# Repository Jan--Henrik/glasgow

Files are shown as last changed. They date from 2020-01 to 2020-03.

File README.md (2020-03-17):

# Glasgow Debug Tool

# This is not the official revC2 branch, I just added USB-C for myself!

**Want one? [Subscribe here](https://mailchi.mp/44980ff6f0ab/glasgow-announcements).**

**Let's chat! Our IRC channel is [#glasgow at freenode.net](https://webchat.freenode.net/?channels=glasgow); our discussion forum is [glasgow.whitequark.org](https://glasgow.whitequark.org/).**

**Important note: if you are looking to assemble boards yourself, use only revC1.**

## What is Glasgow?

Glasgow is a tool for exploring digital interfaces, aimed at embedded developers, reverse engineers, digital archivists, electronics hobbyists, and everyone else who wants to communicate to a wide selection of digital devices with high reliability and minimum hassle. It can be attached to most devices without additional active or passive components, and includes extensive protection from unexpected conditions and operator error.

The Glasgow hardware can support many digital interfaces because it uses reconfigurable logic. Instead of only offering a small selection of standard hardware supported interfaces, it uses an FPGA to adapt on the fly to the task at hand without compromising on performance or reliability, even for unusual, custom or obsolete interfaces.

The Glasgow software is a set of building blocks designed to eliminate incidental complexity. Each interface is packaged into a self-contained *applet* that can be used directly from the command line, or reused as a part of a more complex system. Using Glasgow does not require any programming knowledge, although it becomes much more powerful if you know a bit of Python.

## What can I do with Glasgow?

Some of the tasks Glasgow can do well are:

  * communicate via UART,
    * automatically determine and follow the baud rate of device under test,
  * initiate transactions via SPI or I²C,
  * read and write 24-series EEPROMs,
  * read and write 25-series Flash memories,
    * determine memory parameters via SFDP,
  * read and write ONFI-compatible Flash memories,
    * determine memory parameters via ONFI parameter page,
  * program and verify AVR microcontrollers with SPI interface,
  * automatically determine unknown JTAG pinout,
  * play back JTAG SVF files,
  * debug ARC processors via JTAG,
  * debug some MIPS processors via EJTAG,
  * program and verify XC9500XL CPLDs via JTAG,
  * synthesize sound using a Yamaha OPLx/OPM chip and play it in real time on a webpage,
  * read raw modulated data from 5.25"/3.5" floppy drives,
  * ... and more!

Everything above can be done with only a Glasgow revC board, some wires, and depending on the device under test, external power.

## How does using Glasgow look like?

Watch a typical command-line workflow in this screencast:

asciicast (https://asciinema.org/a/i9edqaUBVLLw7mRZCpdxe91Fu)

## What hardware does Glasgow use?

The Glasgow hardware evolves over time, with each major milestone called a "revision". Although all revisions are, and will always be supported with the same software, they vary significantly in their capabilities, and the chosen revision will limit the possible tasks.

Glasgow boards use a version in the `revXN` format, where `X` is a revision letter (increased on major design changes) and `N` is a stepping number (increased on any layout or component changes). For example, `revC0` is the first stepping of revision C.

### revA/revB

Revisions A and B have not been produced in significant amounts, contain major design issues, and are therefore mostly of historical interest. Nevertheless, everyone who has one of the revA/revB boards can keep using them—forever.

### revC

Overview of the Glasgow PCB

Revision C is the latest revision and is being prepared for mass production. It provides 16 I/O pins with a maximum frequency of approx. 100 MHz\*, independent direction control and independent programmable pull-up/pull-down resistors. The I/O pins are grouped into two I/O ports that can use any voltage from 1.8 V to 5 V, sense and monitor I/O voltage of the device under test, as well as provide up to 150 mA of power. The board uses USB 2 for power, configuration, and communication, achieving up to 336 Mbps (42 MB/s) of sustained combined throughput.

<sub>\* Maximum frequency achievable in practice depends on many factors and will vary greatly with specific interface and applet design. 24 MHz non-DDR can be achieved for most interfaces with minimal effort.</sub>

## What software does Glasgow use?

Glasgow is written entirely in Python 3. The interface logic that runs on the FPGA is described using [Migen](https://m-labs.hk/migen/), which is a Python-based domain specific language. The supporting code that runs on the host PC is written in Python with [asyncio](https://docs.python.org/3/library/asyncio.html). This way, the logic on the FPGA can be assembled on demand for any requested configuration, keeping it as fast and compact as possible, and code can be shared between gateware and software, removing the need to add error-prone "glue" boilerplate.

Glasgow would not be possible without the [open-source iCE40 FPGA toolchain](http://www.clifford.at/icestorm/), which is not only very reliable but also extremely fast. It is so fast that FPGA bitstreams are not cached (beyond not rebuilding the bitstream already on the device), as it only takes a few seconds to build one from scratch for something like an UART. When developing a new applet it is rarely necessary to wait for the toolchain.

Implementing reliable, high-performance USB communication is not trivial—packetization, buffering, and USB quirks add up. Glasgow abstracts away USB: on the FPGA, the applet gateware writes to or reads from a FIFO, and on the host, applet software writes to or reads from a socket-like interface. Idiomatic Python code can communicate at maximum USB 2 bulk bandwidth on a modern PC without additional effort. Moreover, when a future Glasgow revision will use Ethernet in addition to USB, no changes to applet code will be required.

Debugging new applets can be hard, especially if bidirectional buses are involved. Glasgow provides a built-in cycle-accurate logic analyzer that can relate the I/O pin level and direction changes to commands and responses received and sent by the applet. The logic analyzer compresses waveforms and can pause the applet if its buffer is about to overflow.

## How do I use Glasgow?

### ... with Linux?

**Multiple people have reported various issues with the installation instructions below. If any part of these does not work, please file it as a bug, so that the experience can be made more smooth for everyone.**

You will need git, build tools, sdcc, Python 3.7 (or a newer version, in which case replace `3.7` with that version below). On a Debian or Ubuntu system these can be installed with:

    apt-get install --no-install-recommends git build-essential sdcc \
      python3.7 python3-setuptools python3-libusb1 python3-aiohttp python3-bitarray python3-crcmod

You will also need Yosys and nextpnr-ice40, both from the master branch. Follow the setup instructions for [Yosys](https://github.com/yosysHQ/yosys/#setup) and [nextpnr](https://github.com/YosysHQ/nextpnr/#nextpnr-ice40).

Obtain the source code:

    git clone https://github.com/GlasgowEmbedded/glasgow
    cd glasgow
    git submodule update --init vendor/libfx2

Configure your system to allow unprivileged access (for anyone in the `plugdev` group) to the Glasgow hardware:

    sudo cp config/99-glasgow.rules /etc/udev/rules.d

Install the dependencies and the binaries for the current user:

    cd software
    python3.7 setup.py develop --user

The binaries are placed in `$HOME/.local/bin`, so be sure to add that directory to the `PATH` environment variable; after this, you can run `glasgow` from a terminal. Instead of adjusting `PATH` it is also possible to use `python3.7 -m glasgow.cli`.

When you connect your board for the first time after assembly you have to flash it initially, run the following command.

    glasgow factory --rev {A0|B0|C0|C1}

To update the source code, do:

    cd glasgow
    git pull
    cd software
    python3.7 setup.py build_ext

### ... with Windows?

Although first-class Windows support is an important goal and Glasgow already works on Windows, the installation process is not yet ready.

## Who made Glasgow?

  * [@whitequark](https://github.com/whitequark) came up with the design, coordinates the project and implements most of gateware and software;
  * [@awygle](https://github.com/awygle) designed the power/analog port circuitry and helped with layout of revB;
  * [@marcan](https://github.com/marcan) improved almost every aspect of hardware for revC;
  * [@esden](https://github.com/esden) is handling batch manufacturing;
  * [@smunaut](https://github.com/smunaut) provided advice crucial for stability and performance of USB communication;
  * [@electronic_eel](https://github.com/electronic_eel) designed the test jig and advanced protection circuitry;
  * ... and many [other people](https://github.com/GlasgowEmbedded/Glasgow/graphs/contributors).

## License

Glasgow is distributed under the terms of both 0-clause BSD license as well as Apache 2.0 license.

See [LICENSE-0BSD](LICENSE-0BSD.txt) and [LICENSE-Apache-2.0.txt](LICENSE-Apache-2.0.txt) for details.

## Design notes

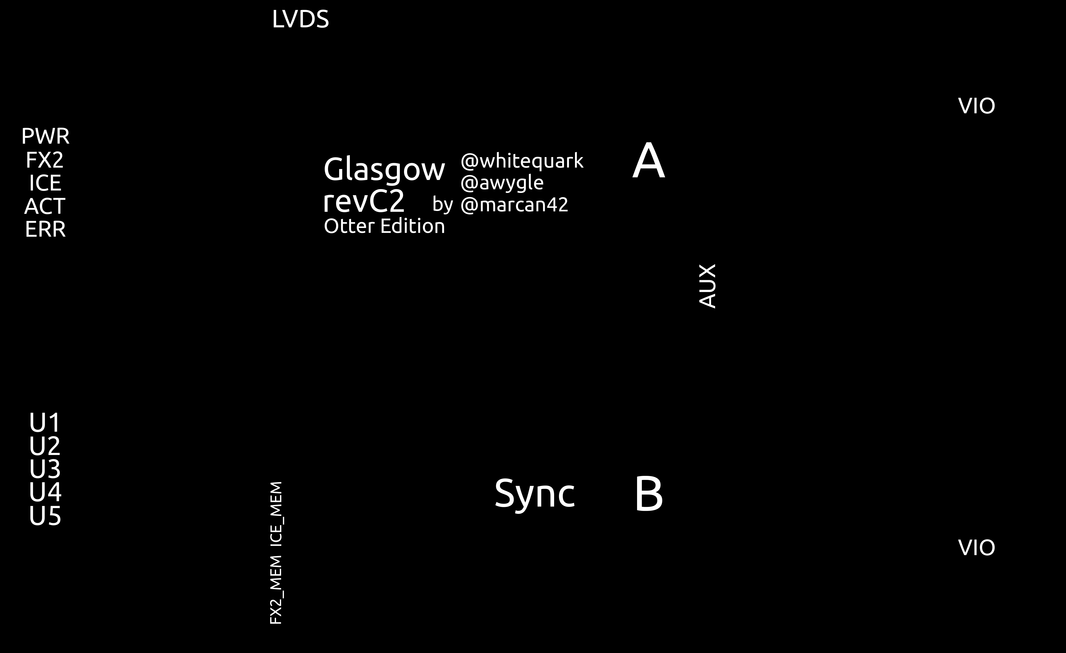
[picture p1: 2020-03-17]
hardware/boards/glasgow/revC1-otter-edition/t_preview.png

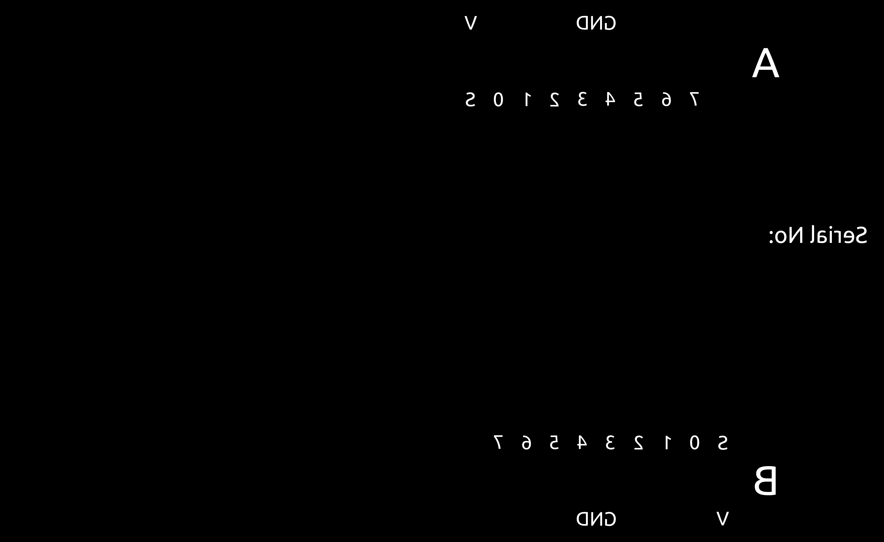
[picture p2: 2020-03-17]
hardware/boards/glasgow/revC1-otter-edition/b_preview.png

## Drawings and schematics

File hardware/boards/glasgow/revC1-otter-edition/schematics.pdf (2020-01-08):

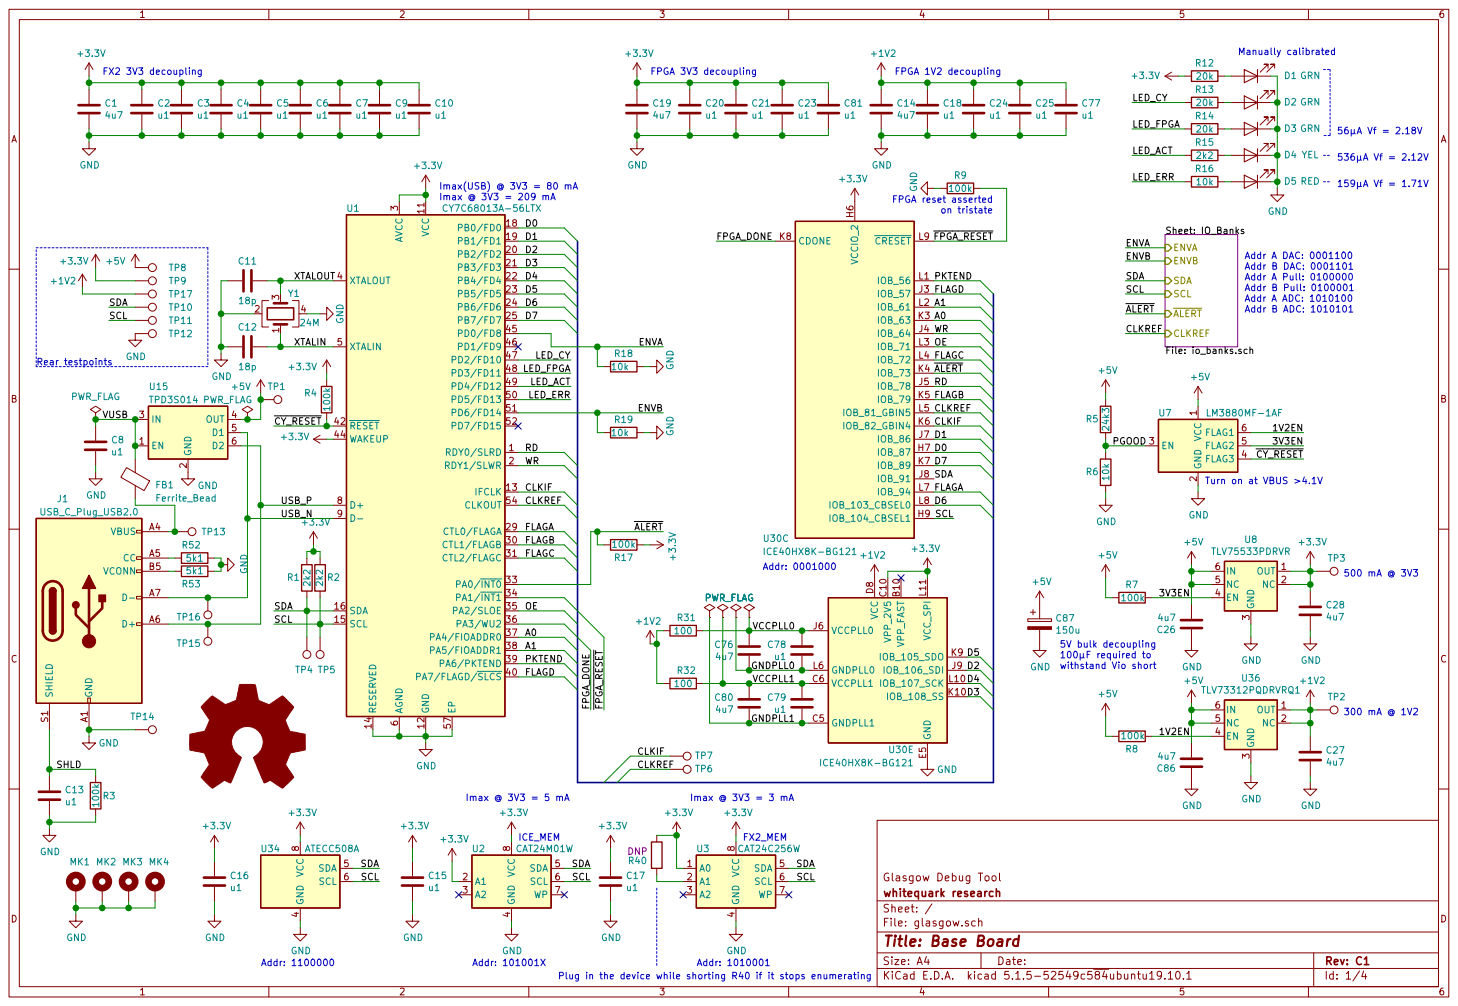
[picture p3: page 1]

3 CTL1/FLAGB 30 CTL2/FLAGC 31 PA0/INT0 33 PA1/INT1 34 PA2/SLOE 35 PA3/WU2 36 PA4/FIOADDR0 37 PA5/FIOADDR1 38 PA6/PKTEND 39 XTALOUT 4 PA7/FLAGD/SLCS 40 RESET 42 WAKEUP 44 PD0/FD8 45 PD1/FD9 46 PD2/FD10 47 PD3/FD11 48 PD4/FD12 49 XTALIN 5 PD5/FD13 50 PD6/FD14 51 PD7/FD15 52 CLKOUT 54 EP 57 AGND

Sheet: IO_Banks File: io_banks.sch ENVA

Addr A DAC: 0001100 Addr B DAC: 0001101 Addr A Pull: 0100000 Addr B Pull: 0100001 Addr A ADC: 1010100 Addr B ADC: 1010101

150u GND
5V bulk decoupling
100µF required to withstand Vio short

4 SDA 5 SCL 6 WP 7 VCC

Glasgow Debug Tool
File: glasgow.sch Sheet: / whitequark research

Id: 1/4 Title: Base Board

Plug in the device while shorting R40 if it stops enumerating

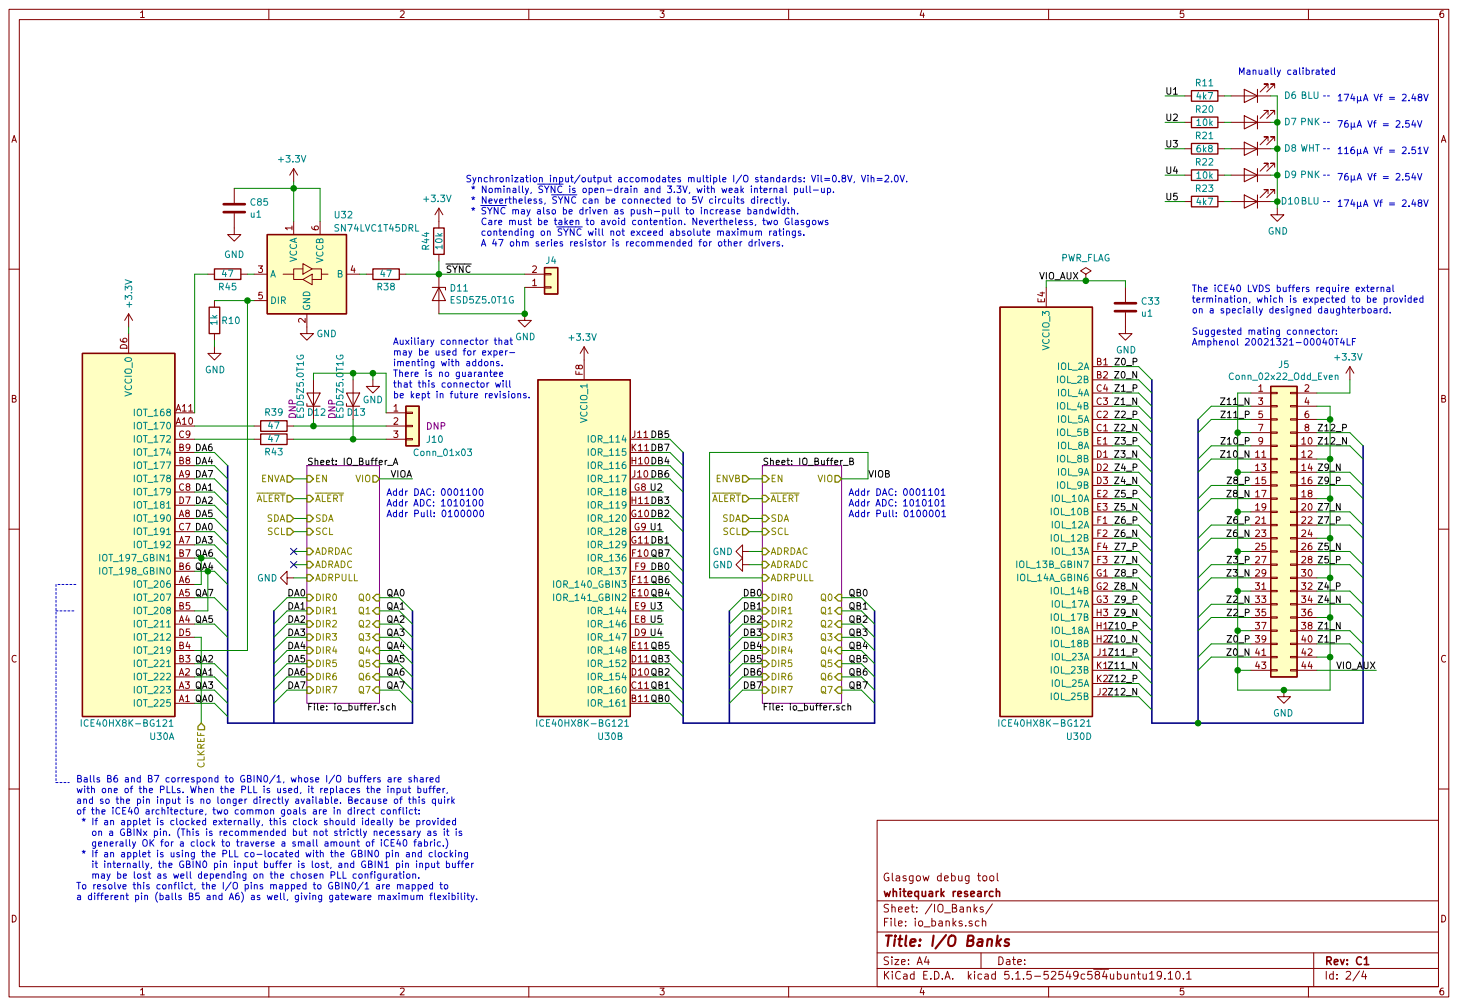
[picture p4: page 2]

Synchronization input/output accomodates multiple I/O standards: Vil=0.8V, Vih=2.0V.
* Nominally, SYNC is open-drain and 3.3V, with weak internal pull-up.
* Nevertheless, SYNC can be connected to 5V circuits directly.
* SYNC may also be driven as push-pull to increase bandwidth.
Care must be taken to avoid contention. Nevertheless, two Glasgows
contending on SYNC will not exceed absolute maximum ratings.

The iCE40 LVDS buffers require external
termination, which is expected to be provided
on a specially designed daughterboard.

may be used for exper-
imenting with addons.
There is no guarantee
that this connector will be kept in future revisions. Addr DAC: 0001100 Addr ADC: 1010100 Addr Pull: 0100000
DIR0 DIR2 DIR4 DIR6 DIR1 DIR3 DIR5 DIR7 ADRPULLVIO
SCL ALERT ADRDAC
File: io_buffer.sch Q1 Q2 Q3 Q4 Q5 Q6 Q7 Q0 SDA

Glasgow debug tool Sheet: IO_Buffer_A

Balls B6 and B7 correspond to GBIN0/1, whose I/O buffers are shared
with one of the PLLs. When the PLL is used, it replaces the input buffer,
and so the pin input is no longer directly available. Because of this quirk
of the iCE40 architecture, two common goals are in direct conflict:
* If an applet is clocked externally, this clock should ideally be provided
on a GBINx pin. (This is recommended but not strictly necessary as it is
generally OK for a clock to traverse a small amount of iCE40 fabric.)
* If an applet is using the PLL co-located with the GBIN0 pin and clocking
it internally, the GBIN0 pin input buffer is lost, and GBIN1 pin input buffer
may be lost as well depending on the chosen PLL configuration.
To resolve this conflict, the I/O pins mapped to GBIN0/1 are mapped to
a different pin (balls B5 and A6) as well, giving gateware maximum flexibility.

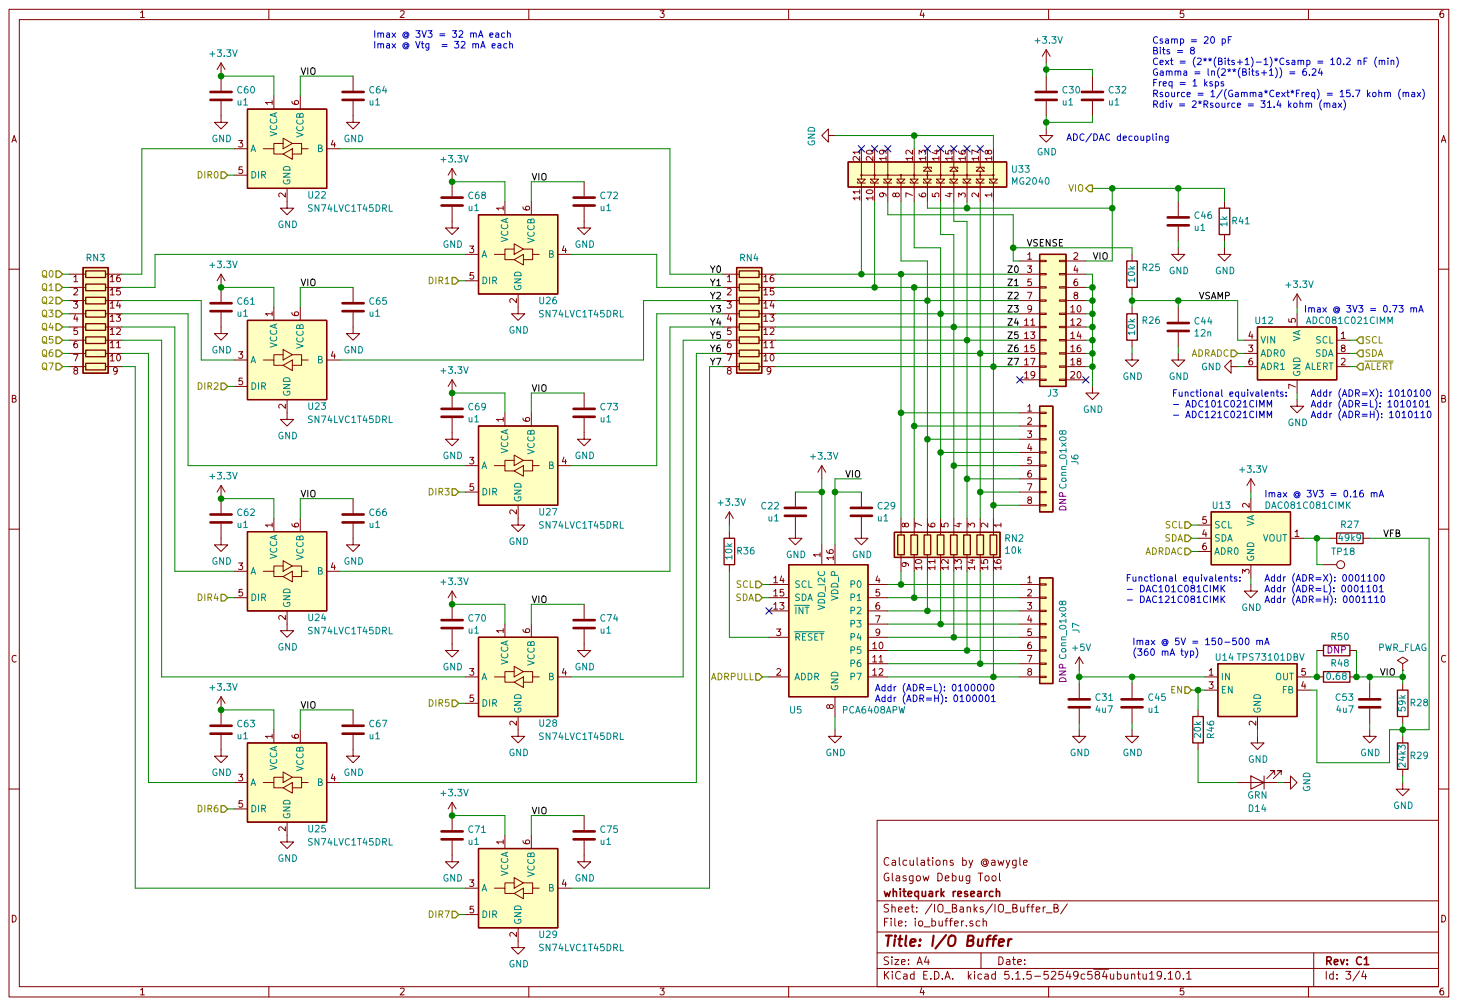
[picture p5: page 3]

Imax @ 3V3 = 32 mA each
Imax @ Vtg = 32 mA each

Csamp = 20 pF Bits = 8 Cext = (2**(Bits+1)-1)*Csamp = 10.2 nF (min)
u1 GND

Gamma = ln(2**(Bits+1)) = 6.24
Freq = 1 ksps
Rsource = 1/(Gamma*Cext*Freq) = 15.7 kohm (max)
Rdiv = 2*Rsource = 31.4 kohm (max)

2 EN 3 FB 4 OUT 5 U14 TPS73101DBV GND GND

Calculations by @awygle GND GND

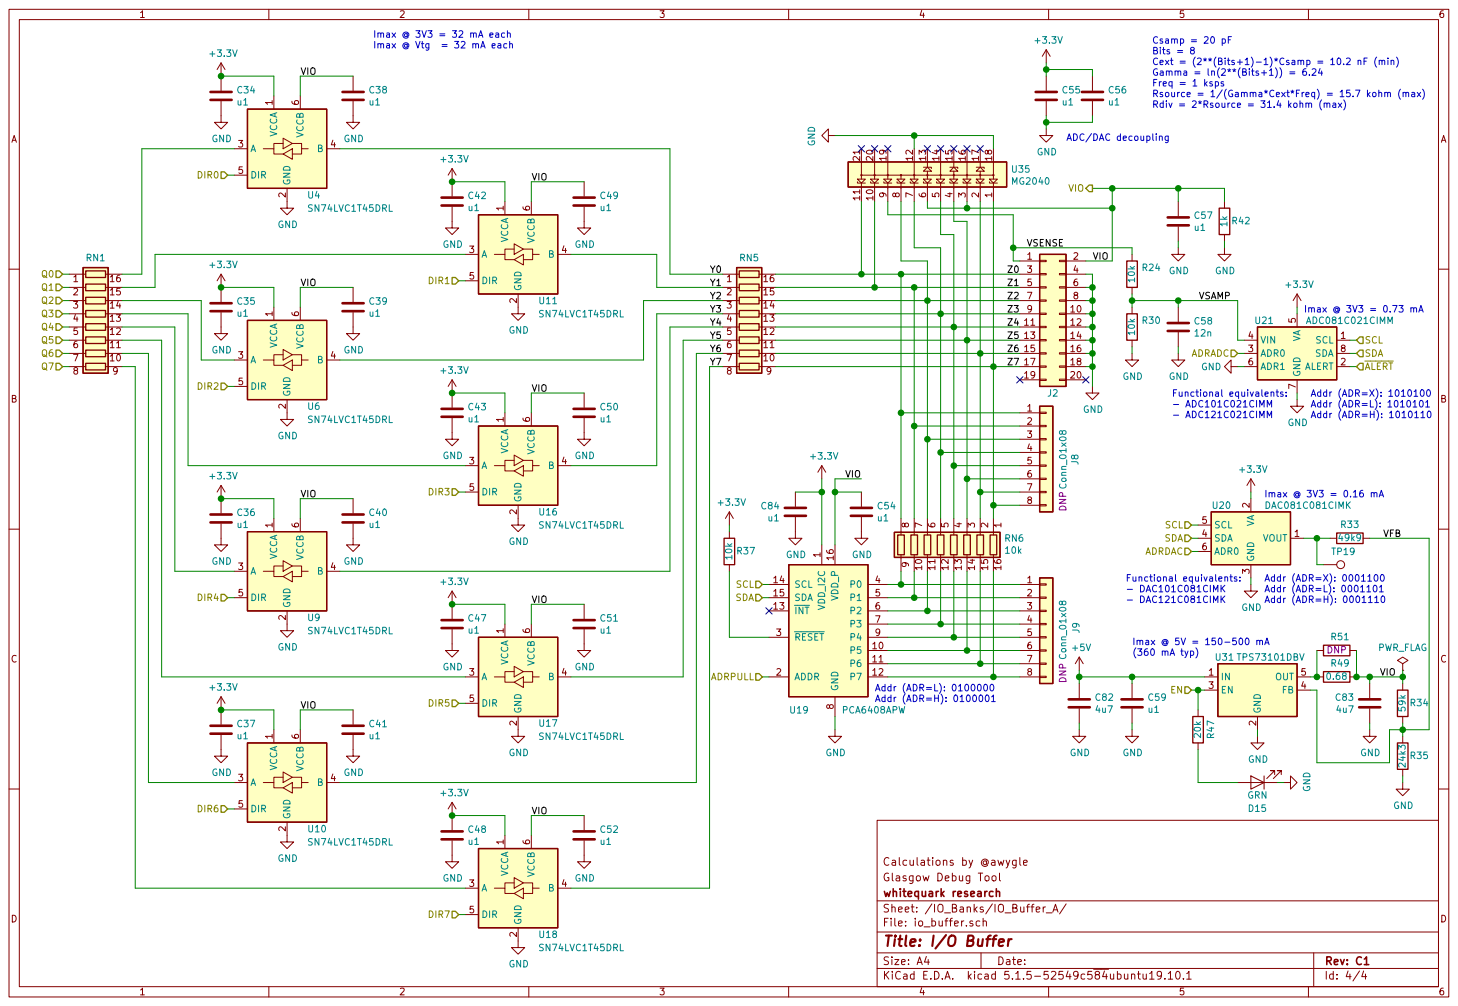
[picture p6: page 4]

Imax @ 3V3 = 32 mA each
Imax @ Vtg = 32 mA each

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

2 EN 3 FB 4 OUT 5 U31 TPS73101DBV GND GND

Calculations by @awygle GND GND

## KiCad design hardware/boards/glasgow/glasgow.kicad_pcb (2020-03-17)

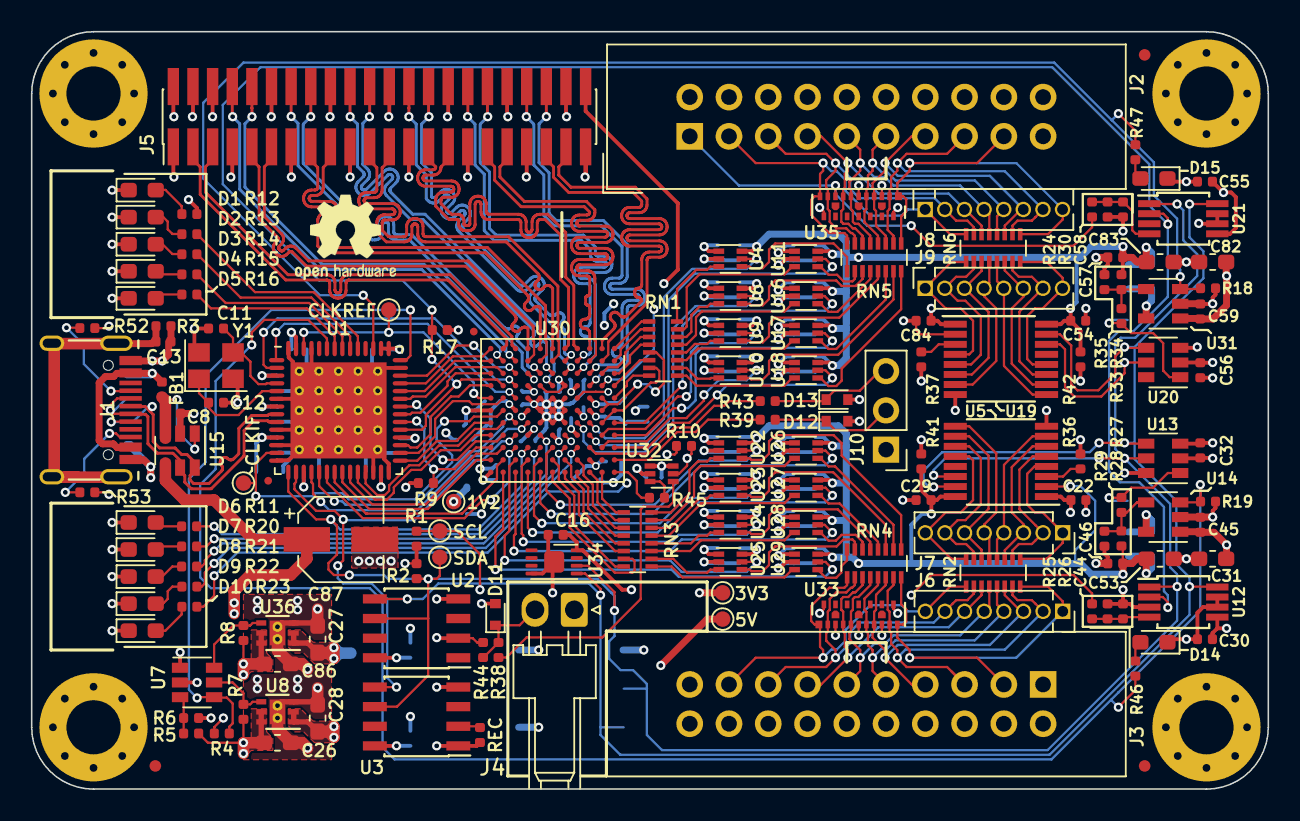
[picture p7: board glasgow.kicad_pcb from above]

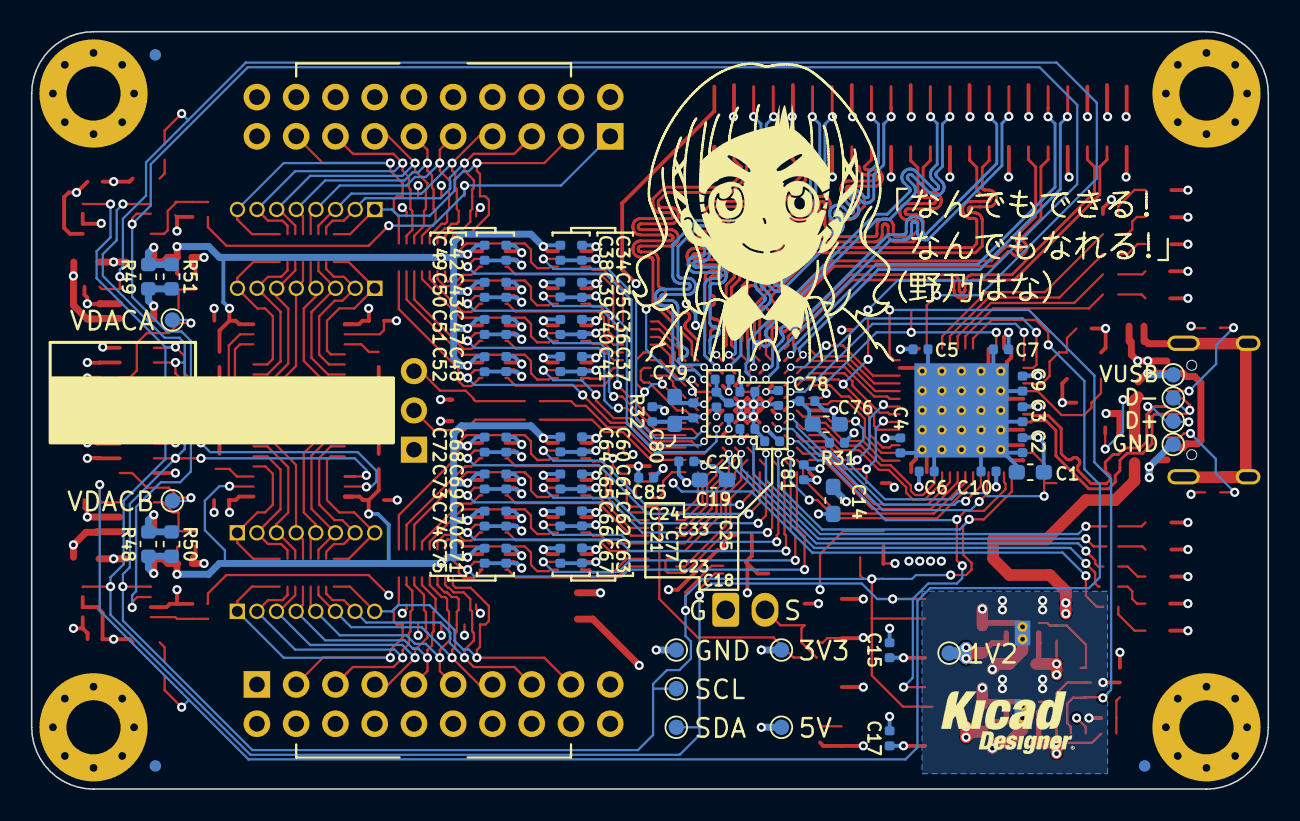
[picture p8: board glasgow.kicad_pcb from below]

Board: 4 copper layers, 80.0 x 49.0 mm, 241 parts (81 on the bottom side), 216 nets.

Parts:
C1, C14, C19, C26, C27, C28, C31, C53, C76, C80, C82, C83, C86: 4u7; C_0603_1608Metric_Pad1.05x0.95mm_HandSolder
C2, C3, C4, C5, C6, C7, C8, C9, C10, C13, C15, C16, C17, C18, C20, C21, C22, C23, C24, C25, C29, C30, C32, C33, C34, C35, C36, C37, C38, C39, C40, C41, C42, C43, C45, C46, C47, C48, C49, C50, C51, C52, C54, C55, C56, C57, C59, C60, C61, C62, C63, C64, C65, C66, C67, C68, C69, C70, C71, C72, C73, C74, C75, C77, C78, C79, C81, C84, C85: u1; C_0402_1005Metric
C11, C12: 18p; C_0402_1005Metric
C44, C58: 12n; C_0402_1005Metric
C87: 150u; CP_Elec_5x3.9
D1, D2, D3, D14, D15: GRN; LED_0603_1608Metric_Pad1.05x0.95mm_HandSolder
D4: YEL; LED_0603_1608Metric_Pad1.05x0.95mm_HandSolder
D5: RED; LED_0603_1608Metric_Pad1.05x0.95mm_HandSolder
D6, D10: BLU; LED_0603_1608Metric_Pad1.05x0.95mm_HandSolder
D7, D9: PNK; LED_0603_1608Metric_Pad1.05x0.95mm_HandSolder
D8: WHT; LED_0603_1608Metric_Pad1.05x0.95mm_HandSolder
D11, D12, D13: ESD5Z5.0T1G; D_SOD-523
FB1: Ferrite_Bead; L_0402_1005Metric
FID1, FID2, FID3, FID4, FID5, FID6: Fiducial_0.75mm_Dia_1.5mm_Outer
FID7, FID8: Fiducial_0.5mm_Dia_1mm_Outer
J1: USB; USB-C 16Pin
J2, J3: Conn_02x10_Odd_Even; IDC-Header_2x10_P2.54mm_Vertical
J4: Conn_01x02; Molex_KK-254_1x02_P2.54mm_Horizontal
J5: Conn_02x22_Odd_Even; PinHeader_2x22_P1.27mm_Vertical_SMD
J6, J7, J8, J9: Conn_01x08; PinSocket_1x08_P1.27mm_Vertical
J10: Conn_01x03; PinHeader_1x03_P2.54mm_Vertical
MK1, MK2, MK3, MK4: Mounting_Hole_PAD; MountingHole_3.5mm_Pad_Via_CrtYd
NONO_HANA: MECHOKKU; nono_hana
R1, R2, R15: 2k2; R_0402_1005Metric
R3, R4, R7, R8, R9, R17: 100k; R_0402_1005Metric
R5, R29, R35: 24k3; R_0402_1005Metric
R6, R16, R18, R19, R20, R22, R24, R25, R26, R30, R36, R37, R44: 10k; R_0402_1005Metric
R10, R41, R42: 1k; R_0402_1005Metric
R11, R23: 4k7; R_0402_1005Metric
R12, R13, R14, R46, R47: 20k; R_0402_1005Metric
R21: 6k8; R_0402_1005Metric
R27, R33: 49k9; R_0402_1005Metric
R28, R34: 59k; R_0402_1005Metric
R31, R32: 100; R_0402_1005Metric
R38, R39, R43, R45: 47; R_0402_1005Metric
R40: DNP; R_0402_1005Metric
R48, R49: 0.68; R_0603_1608Metric
R50, R51: DNP; R_0603_1608Metric
R52, R53: 5k1; R_0402_1005Metric
RN1, RN3, RN4, RN5: 33; R_Array_Convex_8x0602
RN2, RN6: 10k; R_Array_Convex_8x0602
TP1, TP8: 5V; TestPoint_Pad_D1.0mm
TP2, TP17: 1V2; TestPoint_Pad_D1.0mm
TP3, TP7, TP9: 3V3; TestPoint_Pad_D1.0mm
TP4, TP10: SDA; TestPoint_Pad_D1.0mm
TP5, TP11: SCL; TestPoint_Pad_D1.0mm
TP6: CLKREF; TestPoint_Pad_D1.0mm
TP12: GND; TestPoint_Pad_D1.0mm
TP13: VBUS; TestPoint_Pad_D1.0mm
TP14: USBGND; TestPoint_Pad_D1.0mm
TP15: USBDP; TestPoint_Pad_D1.0mm
TP16: USBDM; TestPoint_Pad_D1.0mm
TP18, TP19: VDAC; TestPoint_Pad_D1.0mm
U1: CY7C68013A-56LTX; Cypress_QFN-56-1EP_8x8mm_P0.5mm_EP6.22x6.22mm_ThermalVias
U2: CAT24M01W; SOIC-8_3.9x4.9mm_P1.27mm
U3: CAT24C256W; SOIC-8_3.9x4.9mm_P1.27mm
U4, U6, U9, U10, U11, U16, U17, U18, U22, U23, U24, U25, U26, U27, U28, U29, U32: SN74LVC1T45DRL; SOT-563
U5, U19: PCA6408APW; TSSOP-16_4.4x5mm_P0.65mm
U7: LM3880MF-1AF; SOT-23-6
U8: TLV75533PDRVR; DFN-6-1EP_2x2mm_P0.65mm_EP1x1.6mm_ThermalVias
U12, U21: ADC081C021CIMM; MSOP-8_3x3mm_P0.65mm
U13, U20: DAC081C081CIMK; SOT-23-6
U14, U31: TPS73101DBV; SOT-23-5
U15: TPD3S014; SOT-23-6
U30: ICE40HX8K-BG121; BGA-121_9.0x9.0mm_Layout11x11_P0.8mm_Ball0.4mm_Pad0.35mm_NS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
U33, U35: MG2040; UDFN-18-3EP_5.5x1.5mm_P0.5mm_EP0.5x0.5mm
U34: ATECC508A; WDFN-8-1EP_3x2mm_P0.5mm_EP1.3x1.4mm
U36: TLV73312PQDRVRQ1; DFN-6-1EP_2x2mm_P0.65mm_EP1x1.6mm_ThermalVias
Y1: 24M; Crystal_SMD_3225-4Pin_3.2x2.5mm

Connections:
+1V2: C14.1, C18.1, C24.1, C25.1, C27.1, C77.1, R31.2, R32.2, TP2.1, TP17.1, U30.D4, U30.D8, U30.H4, U30.H8, U36.1, U36.2
+3V3: C1.1, C2.1, C3.1, C4.1, C5.1, C6.1, C7.1, C9.1, C10.1, C15.1, C16.1, C17.1, C19.1, C20.1, C21.1, C22.1, C23.1, C28.1, C30.1, C32.1, C34.1, C35.1, C36.1, C37.1, C42.1, C43.1, C47.1, C48.1, C55.1, C56.1, C60.1, C61.1, C62.1, C63.1, C68.1, C69.1, C70.1, C71.1, C81.1, C84.1, C85.1, J5.2, R1.2, R2.2, R4.2, R12.1, R17.2, R36.2, R37.2, R40.2, R44.2, TP3.1, TP9.1, U1.3, U1.7, U1.11, U1.17, U1.27, U1.32, U1.43, U1.44, U1.55, U2.2, U2.8, U3.1, U3.8, U4.1, U5.1, U6.1, U8.1, U8.2, U9.1, U10.1, U11.1, U12.5, U13.2, U16.1, U17.1, U18.1, U19.1, U20.2, U21.5, U22.1, U23.1, U24.1, U25.1, U26.1, U27.1, U28.1, U29.1, U30.C10, U30.D6, U30.F8, U30.H6, U30.L11, U32.1, U32.6, U34.8
+5V: C26.2, C31.1, C45.1, C59.1, C82.1, C86.2, C87.1, R5.2, R7.2, R8.2, TP1.1, TP8.1, U7.1, U8.5, U8.6, U14.1, U15.4, U31.1, U36.5, U36.6
/1V2EN: R8.1, U7.6, U36.4
/3V3EN: R7.1, U7.5, U8.4
/A0: U1.37, U30.K3
/A1: U1.38, U30.L2
/CLKIF: TP7.1, U1.13, U30.K6
/CLKREF: TP6.1, U1.54, U30.D5, U30.L5
/D0: U1.18, U30.H7
/D1: U1.19, U30.J7
/D2: U1.20, U30.J9
/D3: U1.21, U30.K10
/D4: U1.22, U30.L10
/D5: U1.23, U30.K9
/D6: U1.24, U30.L8
/D7: U1.25, U30.K7
/ENVA: R18.1, R47.1, U1.45, U31.3
/ENVB: R19.1, R46.1, U1.51, U14.3
/FLAGA: U1.29, U30.L7
/FLAGB: U1.30, U30.K5
/FLAGC: U1.31, U30.L4
/FLAGD: U1.40, U30.J3
/FPGA_DONE: U1.36, U30.K8
/GNDPLL0: C76.2, C78.2, U30.L6
/GNDPLL1: C79.2, C80.2, U30.C5
/IO_Banks/DA0: U4.5, U30.C7
/IO_Banks/DA1: U11.5, U30.C8
/IO_Banks/DA2: U6.5, U30.D7
/IO_Banks/DA3: U16.5, U30.A7
/IO_Banks/DA4: U9.5, U30.B8
/IO_Banks/DA5: U17.5, U30.A8
/IO_Banks/DA6: U10.5, U30.B9
/IO_Banks/DA7: U18.5, U30.A9
/IO_Banks/DB0: U22.5, U30.F9
/IO_Banks/DB1: U26.5, U30.G11
/IO_Banks/DB2: U23.5, U30.G10
/IO_Banks/DB3: U27.5, U30.H11
/IO_Banks/DB4: U24.5, U30.H10
/IO_Banks/DB5: U28.5, U30.J11
/IO_Banks/DB6: U25.5, U30.J10
/IO_Banks/DB7: U29.5, U30.K11
/IO_Banks/IO_Buffer_A/VFB: R33.2, R34.1, R35.2, U31.4
/IO_Banks/IO_Buffer_A/VSAMP: C58.1, R24.1, R30.2, U21.4
/IO_Banks/IO_Buffer_A/VSENSE: J2.1, R24.2, U35.9
/IO_Banks/IO_Buffer_A/Y0: RN5.1, U4.4
/IO_Banks/IO_Buffer_A/Y1: RN5.2, U11.4
/IO_Banks/IO_Buffer_A/Y2: RN5.3, U6.4
/IO_Banks/IO_Buffer_A/Y3: RN5.4, U16.4
/IO_Banks/IO_Buffer_A/Y4: RN5.5, U9.4
/IO_Banks/IO_Buffer_A/Y5: RN5.6, U17.4
/IO_Banks/IO_Buffer_A/Y6: RN5.7, U10.4
/IO_Banks/IO_Buffer_A/Y7: RN5.8, U18.4
/IO_Banks/IO_Buffer_A/Z0: J2.3, J8.1, RN5.16, RN6.8, U35.11
/IO_Banks/IO_Buffer_A/Z1: J2.5, J8.2, RN5.15, RN6.7, U35.10
/IO_Banks/IO_Buffer_A/Z2: J2.7, J8.3, RN5.14, RN6.6, U35.8
/IO_Banks/IO_Buffer_A/Z3: J2.9, J8.4, RN5.13, RN6.5, U35.7
/IO_Banks/IO_Buffer_A/Z4: J2.11, J8.5, RN5.12, RN6.4, U35.5
/IO_Banks/IO_Buffer_A/Z5: J2.13, J8.6, RN5.11, RN6.3, U35.4
/IO_Banks/IO_Buffer_A/Z6: J2.15, J8.7, RN5.10, RN6.2, U35.2
/IO_Banks/IO_Buffer_A/Z7: J2.17, J8.8, RN5.9, RN6.1, U35.1
/IO_Banks/IO_Buffer_B/VFB: R27.2, R28.1, R29.2, U14.4
/IO_Banks/IO_Buffer_B/VSAMP: C44.1, R25.1, R26.2, U12.4
/IO_Banks/IO_Buffer_B/VSENSE: J3.1, R25.2, U33.9
/IO_Banks/IO_Buffer_B/Y0: RN4.1, U22.4
/IO_Banks/IO_Buffer_B/Y1: RN4.2, U26.4
/IO_Banks/IO_Buffer_B/Y2: RN4.3, U23.4
/IO_Banks/IO_Buffer_B/Y3: RN4.4, U27.4
/IO_Banks/IO_Buffer_B/Y4: RN4.5, U24.4
/IO_Banks/IO_Buffer_B/Y5: RN4.6, U28.4
/IO_Banks/IO_Buffer_B/Y6: RN4.7, U25.4
/IO_Banks/IO_Buffer_B/Y7: RN4.8, U29.4
/IO_Banks/IO_Buffer_B/Z0: J3.3, J6.1, RN2.8, RN4.16, U33.11
/IO_Banks/IO_Buffer_B/Z1: J3.5, J6.2, RN2.7, RN4.15, U33.10
/IO_Banks/IO_Buffer_B/Z2: J3.7, J6.3, RN2.6, RN4.14, U33.8
/IO_Banks/IO_Buffer_B/Z3: J3.9, J6.4, RN2.5, RN4.13, U33.7
/IO_Banks/IO_Buffer_B/Z4: J3.11, J6.5, RN2.4, RN4.12, U33.5
/IO_Banks/IO_Buffer_B/Z5: J3.13, J6.6, RN2.3, RN4.11, U33.4
/IO_Banks/IO_Buffer_B/Z6: J3.15, J6.7, RN2.2, RN4.10, U33.2
/IO_Banks/IO_Buffer_B/Z7: J3.17, J6.8, RN2.1, RN4.9, U33.1
/IO_Banks/QA0: RN1.1, U30.A1
/IO_Banks/QA1: RN1.2, U30.A2
/IO_Banks/QA2: RN1.3, U30.B3
/IO_Banks/QA3: RN1.4, U30.A3
/IO_Banks/QA4: RN1.5, U30.B5, U30.B6
/IO_Banks/QA5: RN1.6, U30.A4
/IO_Banks/QA6: RN1.7, U30.A6, U30.B7
/IO_Banks/QA7: RN1.8, U30.A5
/IO_Banks/QB0: RN3.1, U30.B11
/IO_Banks/QB1: RN3.2, U30.C11
/IO_Banks/QB2: RN3.3, U30.D10
/IO_Banks/QB3: RN3.4, U30.D11
/IO_Banks/QB4: RN3.5, U30.E10
/IO_Banks/QB5: RN3.6, U30.E11
/IO_Banks/QB6: RN3.7, U30.F11
/IO_Banks/QB7: RN3.8, U30.F10
/IO_Banks/U1: R11.1, U30.G9
/IO_Banks/U2: R20.1, U30.G8
/IO_Banks/U3: R21.1, U30.E9
/IO_Banks/U4: R22.1, U30.D9
/IO_Banks/U5: R23.1, U30.E8
/IO_Banks/VIOA: C38.1, C39.1, C40.1, C41.1, C49.1, C50.1, C51.1, C52.1, C54.1, C57.1, C83.1, J2.2, R34.2, R42.2, R49.2, R51.2, U4.6, U6.6, U9.6, U10.6, U11.6, U16.6, U17.6, U18.6, U19.16, U35.3, U35.6
/IO_Banks/VIOB: C29.1, C46.1, C53.1, C64.1, C65.1, C66.1, C67.1, C72.1, C73.1, C74.1, C75.1, J3.2, R28.2, R41.2, R48.2, R50.2, U5.2, U5.16, U22.6, U23.6, U24.6, U25.6, U26.6, U27.6, U28.6, U29.6, U33.3, U33.6
/IO_Banks/VIO_AUX: C33.1, J5.44, U30.E4, U30.G4
/IO_Banks/Z0_N: J5.41, U30.B2
/IO_Banks/Z0_P: J5.39, U30.B1
/IO_Banks/Z1_N: J5.38, U30.C3
/IO_Banks/Z1_P: J5.40, U30.C4
/IO_Banks/Z2_N: J5.33, U30.C1
/IO_Banks/Z2_P: J5.35, U30.C2
/IO_Banks/Z3_N: J5.29, U30.D1
/IO_Banks/Z3_P: J5.27, U30.E1
/IO_Banks/Z4_N: J5.34, U30.D3
/IO_Banks/Z4_P: J5.32, U30.D2
/IO_Banks/Z5_N: J5.26, U30.E3
/IO_Banks/Z5_P: J5.28, U30.E2
/IO_Banks/Z6_N: J5.23, U30.F2
/IO_Banks/Z6_P: J5.21, U30.F1
/IO_Banks/Z7_N: J5.20, U30.F3
/IO_Banks/Z7_P: J5.22, U30.F4
/IO_Banks/Z8_N: J5.17, U30.G2
/IO_Banks/Z8_P: J5.15, U30.G1
/IO_Banks/Z9_N: J5.14, U30.H3
/IO_Banks/Z9_P: J5.16, U30.G3
/IO_Banks/Z10_N: J5.11, U30.H2
/IO_Banks/Z10_P: J5.9, U30.H1
/IO_Banks/Z11_N: J5.3, U30.K1
/IO_Banks/Z11_P: J5.5, U30.J1
/IO_Banks/Z12_N: J5.10, U30.J2
/IO_Banks/Z12_P: J5.8, U30.K2
/IO_Banks/~SYNC: D11.1, J4.2, R38.1, R44.1
/LED_ACT: R15.1, U1.49
/LED_CY: R13.1, U1.47
/LED_ERR: R16.1, U1.50
/LED_FPGA: R14.1, U1.48
/OE: U1.35, U30.L3
/PGOOD: R5.1, R6.2, U7.3
/PKTEND: U1.39, U30.L1
/RD: U1.1, U30.J5
/SCL: R2.1, TP5.1, TP11.1, U1.15, U2.6, U3.6, U5.14, U12.1, U13.5, U19.14, U20.5, U21.1, U30.H9, U34.6
/SDA: R1.1, TP4.1, TP10.1, U1.16, U2.5, U3.5, U5.15, U12.8, U13.4, U19.15, U20.4, U21.8, U30.J8, U34.5
/SHLD: C13.1, J1.S1, R3.1
/USB_N: J1.A7, J1.B7, TP16.1, U1.9, U15.5
/USB_P: J1.A6, J1.B6, TP15.1, U1.8, U15.6
/VCCPLL0: C76.1, C78.1, R31.1, U30.J6
/VCCPLL1: C79.1, C80.1, R32.1, U30.C6
/VUSB: C8.1, FB1.2, U15.1, U15.3
/WR: U1.2, U30.J4
/XTALIN: C12.1, U1.5, Y1.1
/XTALOUT: C11.1, U1.4, Y1.3
/~ALERT: R17.1, U1.33, U12.2, U21.2, U30.K4
/~CY_RESET: R4.1, U1.42, U7.4
/~FPGA_RESET: R9.2, U1.34, U30.L9
GND: C1.2, C2.2, C3.2, C4.2, C5.2, C6.2, C7.2, C8.2, C9.2, C10.2, C11.2, C12.2, C13.2, C14.2, C15.2, C16.2, C17.2, C18.2, C19.2, C20.2, C21.2, C22.2, C23.2, C24.2, C25.2, C26.1, C27.2, C28.2, C29.2, C30.2, C31.2, C32.2, C33.2, C34.2, C35.2, C36.2, C37.2, C38.2, C39.2, C40.2, C41.2, C42.2, C43.2, C44.2, C45.2, C46.2, C47.2, C48.2, C49.2, C50.2, C51.2, C52.2, C53.2, C54.2, C55.2, C56.2, C57.2, C58.2, C59.2, C60.2, C61.2, C62.2, C63.2, C64.2, C65.2, C66.2, C67.2, C68.2, C69.2, C70.2, C71.2, C72.2, C73.2, C74.2, C75.2, C77.2, C81.2, C82.2, C83.2, C84.2, C85.2, C86.1, C87.2, D1.1, D2.1, D3.1, D4.1, D5.1, D6.1, D7.1, D8.1, D9.1, D10.1, D11.2, D12.2, D13.2, D14.1, D15.1, J1.A1, J1.A12, J1.B1, J1.B12, J2.4, J2.6, J2.8, J2.10, J2.12, J2.14, J2.16, J2.18, J3.4, J3.6, J3.8, J3.10, J3.12, J3.14, J3.16, J3.18, J4.1, J5.1, J5.4, J5.6, J5.7, J5.12, J5.13, J5.18, J5.19, J5.24, J5.25, J5.30, J5.31, J5.36, J5.37, J5.42, J5.43, J10.1, MK1.1, MK2.1, MK3.1, MK4.1, R3.2, R6.1, R9.1, R10.2, R18.2, R19.2, R26.1, R29.1, R30.1, R35.1, R41.1, R42.1, R52.1, R53.1, TP12.1, TP14.1, U1.6, U1.10, U1.12, U1.14, U1.26, U1.28, U1.41, U1.53, U1.56, U1.57, U2.4, U3.4, U4.2, U5.8, U6.2, U7.2, U8.3, U8.7, U9.2, U10.2, U11.2, U12.3, U12.6, U12.7, U13.3, U13.6, U14.2, U15.2, U16.2, U17.2, U18.2, U19.2, U19.8, U20.3, U21.6, U21.7, U22.2, U23.2, U24.2, U25.2, U26.2, U27.2, U28.2, U29.2, U30.E5, U30.E6, U30.E7, U30.F5, U30.F6, U30.F7, U30.G5, U30.G6, U30.G7, U30.H5, U31.2, U32.2, U33.12, U33.18, U34.4, U34.9, U35.12, U35.18, U36.3, U36.7, Y1.2, Y1.4
unnamed: D1.2, R12.2
unnamed: D2.2, R13.2
unnamed: D3.2, R14.2
unnamed: D4.2, R15.2
unnamed: D5.2, R16.2
unnamed: D6.2, R11.2
unnamed: D7.2, R20.2
unnamed: D8.2, R21.2
unnamed: D9.2, R22.2
unnamed: D10.2, R23.2
unnamed: D12.1, J10.2, R39.1
unnamed: D13.1, J10.3, R43.1
unnamed: D14.2, R46.2
unnamed: D15.2, R47.2
unnamed: FB1.1, J1.A4, J1.A9, J1.B4, J1.B9, TP13.1
unnamed: J1.A5, R52.2
unnamed: J1.B5, R53.2
unnamed: J7.1, RN2.9, U5.4
unnamed: J7.2, RN2.10, U5.5
unnamed: J7.3, RN2.11, U5.6
unnamed: J7.4, RN2.12, U5.7
unnamed: J7.5, RN2.13, U5.9
unnamed: J7.6, RN2.14, U5.10
unnamed: J7.7, RN2.15, U5.11
unnamed: J7.8, RN2.16, U5.12
unnamed: J9.1, RN6.9, U19.4
unnamed: J9.2, RN6.10, U19.5
unnamed: J9.3, RN6.11, U19.6
unnamed: J9.4, RN6.12, U19.7
unnamed: J9.5, RN6.13, U19.9
unnamed: J9.6, RN6.14, U19.10
unnamed: J9.7, RN6.15, U19.11
unnamed: J9.8, RN6.16, U19.12
unnamed: R10.1, U30.B4, U32.5
unnamed: R27.1, TP18.1, U13.1
unnamed: R33.1, TP19.1, U20.1
unnamed: R36.1, U5.3
unnamed: R37.1, U19.3
unnamed: R38.2, U32.4
unnamed: R39.2, U30.A10
unnamed: R40.1, U3.2
unnamed: R43.2, U30.C9
unnamed: R45.1, U32.3
unnamed: R45.2, U30.A11
unnamed: R48.1, R50.1, U14.5
unnamed: R49.1, R51.1, U31.5
unnamed: RN1.9, U18.3
unnamed: RN1.10, U10.3
unnamed: RN1.11, U17.3
unnamed: RN1.12, U9.3
unnamed: RN1.13, U16.3
unnamed: RN1.14, U6.3
unnamed: RN1.15, U11.3
unnamed: RN1.16, U4.3
unnamed: RN3.9, U29.3
unnamed: RN3.10, U25.3
unnamed: RN3.11, U28.3
unnamed: RN3.12, U24.3
unnamed: RN3.13, U27.3
unnamed: RN3.14, U23.3
unnamed: RN3.15, U26.3
unnamed: RN3.16, U22.3

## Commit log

2020-01-08 revC2: added output files
    [glasgow-B_Cu.gbl, glasgow-B_Mask.gbs, glasgow-B_Paste.gbp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]
2020-03-17 added revC1 otter edition gerber
    [glasgow-B_Cu.gbl, glasgow-B_Mask.gbs, glasgow-B_Paste.gbp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]
